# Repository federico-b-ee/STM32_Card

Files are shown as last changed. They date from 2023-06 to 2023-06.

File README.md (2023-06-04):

# STM32_Card
This is the first PCB I have designed and professionally assembled. I used KiCAD v7 and JLC PCBs' services.

# Schematic and 3D-view 

SCH
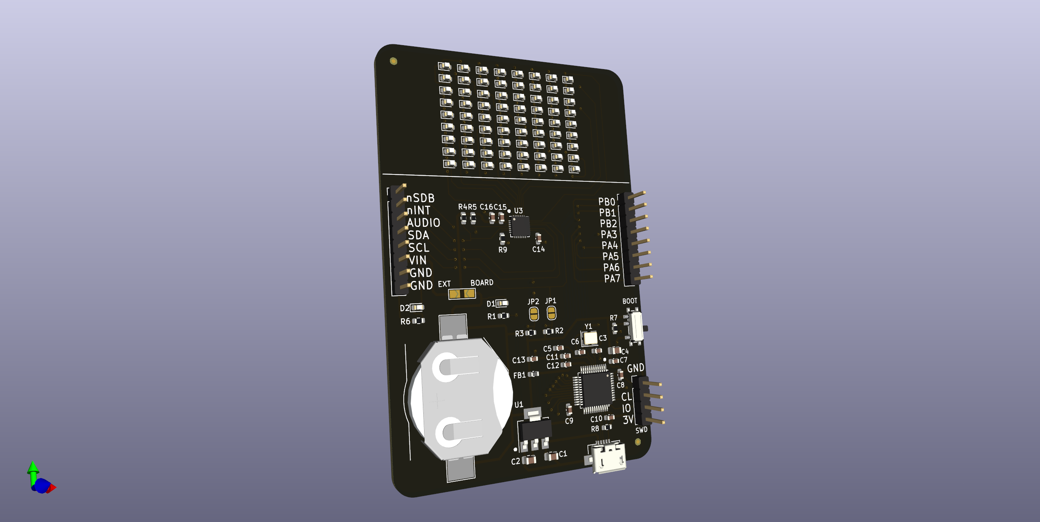
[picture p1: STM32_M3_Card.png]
3D


# Picture and Demo
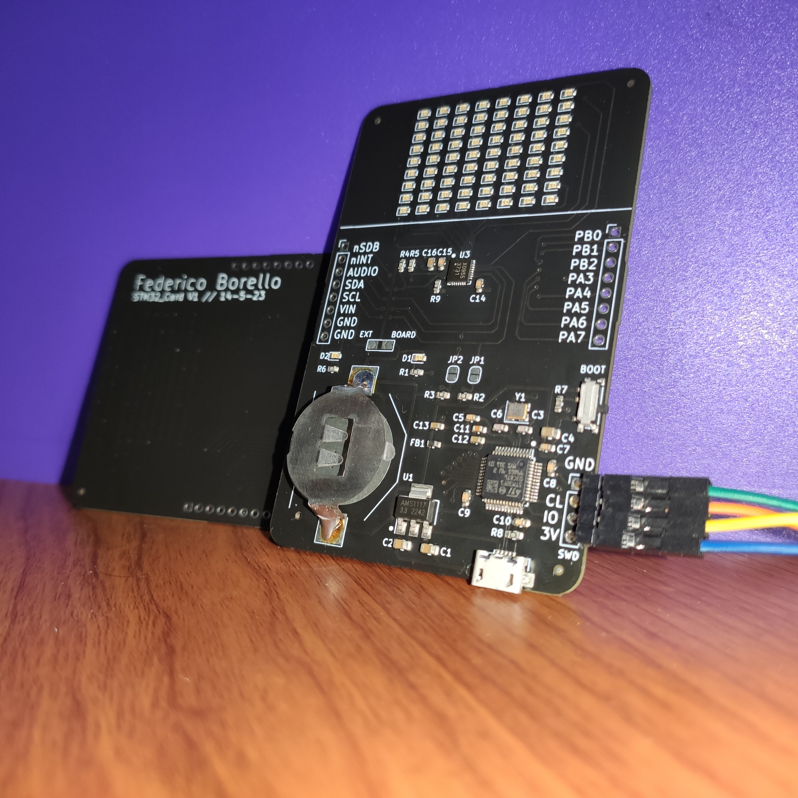
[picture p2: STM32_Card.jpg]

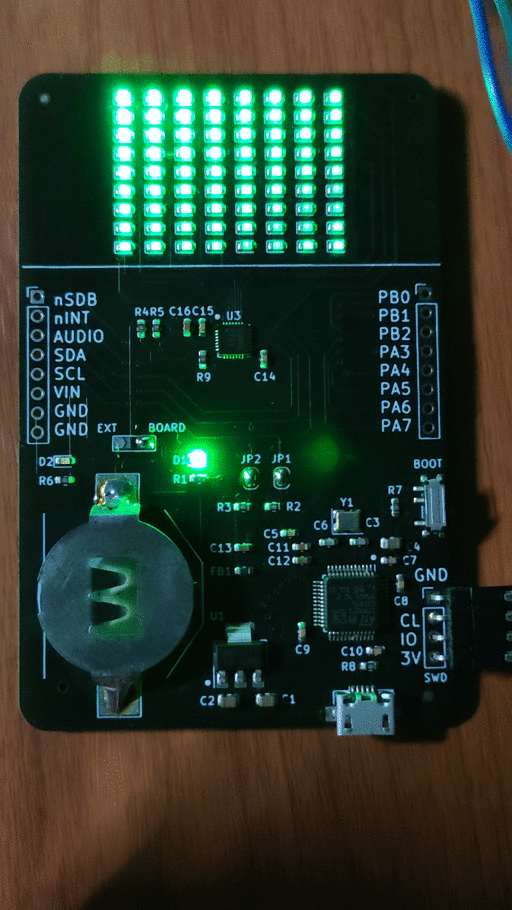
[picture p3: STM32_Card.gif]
DEMO


*Note: The gif above was made using the Adafruit's Demo:

- [Library](https://github.com/adafruit/Adafruit_IS31FL3731)
- [Overview](https://learn.adafruit.com/i31fl3731-16x9-charliplexed-pwm-led-driver/overview)

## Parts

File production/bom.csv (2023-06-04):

Designator | Footprint | Quantity | Value | LCSC Part #
C1, C2 | 0805 | 2 | 22u
C10, C14, C15, C5, C7, C8, C9 | 0603 | 7 | 100n
C11 | 0603 | 1 | 10n
C12, C13, C16 | 0603 | 3 | 1u
C3, C6 | 0603 | 2 | 10p
C4 | 0805 | 1 | 10u
D1, D10, D11, D12, D13, D14, D15, D16, D17, D18, D19, D2, D20, D21, D22, D23, D24, D25, D26, D27, D28, D29, D3, D30, D31, D32, D33, D34, D35, D36, D37, D38, D39, D4, D40, D41, D42, D43, D44, D45, D46, D47, D48, D49, D5, D50, D51, D52, D53, D54, D55, D56, D57, D58, D59, D6, D60, D61, D62, D63, D64, D65, D66, D67, D68, D69, D7, D70, D71, D72, D73, D74, D8, D9 | 0603 | 74 | LED (RED)
FB1 | 0603 | 1 | 120R | C108298
J2 | USB_Micro-B_Amphenol_10104110_Horizontal | 1 | USB_B_Micro | C2972784
JP1, JP2 | SolderJumper-2_P1.3mm_Open_RoundedPad1.0x1.5mm | 2 | SolderJumper_2_Open
JP4 | SolderJumper-3_P2.0mm_Open_TrianglePad1.0x1.5mm_NumberLabels | 1 | SolderJumper_3_Open
R1, R6 | 0603 | 2 | 680R
R2, R3, R8 | 0603 | 3 | 1k5
R4, R5, R7, R9 | 0603 | 4 | 18k
SW1 | SW_SPDT_PCM12 | 1 | SW_SPDT | C221841
U1 | SOT-223-3_TabPin2 | 1 | AMS1117-3.3 | C2992570
U2 | LQFP-48_7x7mm_P0.5mm | 1 | STM32F103C8T6 | C8734
U3 | QFN-28-1EP_4x4mm_P0.4mm_EP2.3x2.3mm | 1 | IS31FL3731-QF | C191206
Y1 | Crystal_SMD_3225-4Pin_3.2x2.5mm | 1 | 16MHz 10pF | C13738

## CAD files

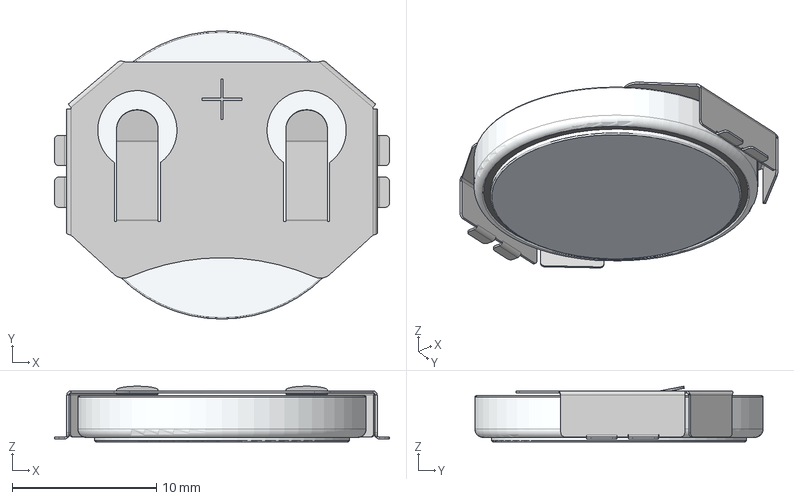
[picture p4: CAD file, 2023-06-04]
PCB/CR2032_closed_battery_BH.step
23.2 x 20.0 x 3.86 mm
cr2032 smd holder
CR2032 battery

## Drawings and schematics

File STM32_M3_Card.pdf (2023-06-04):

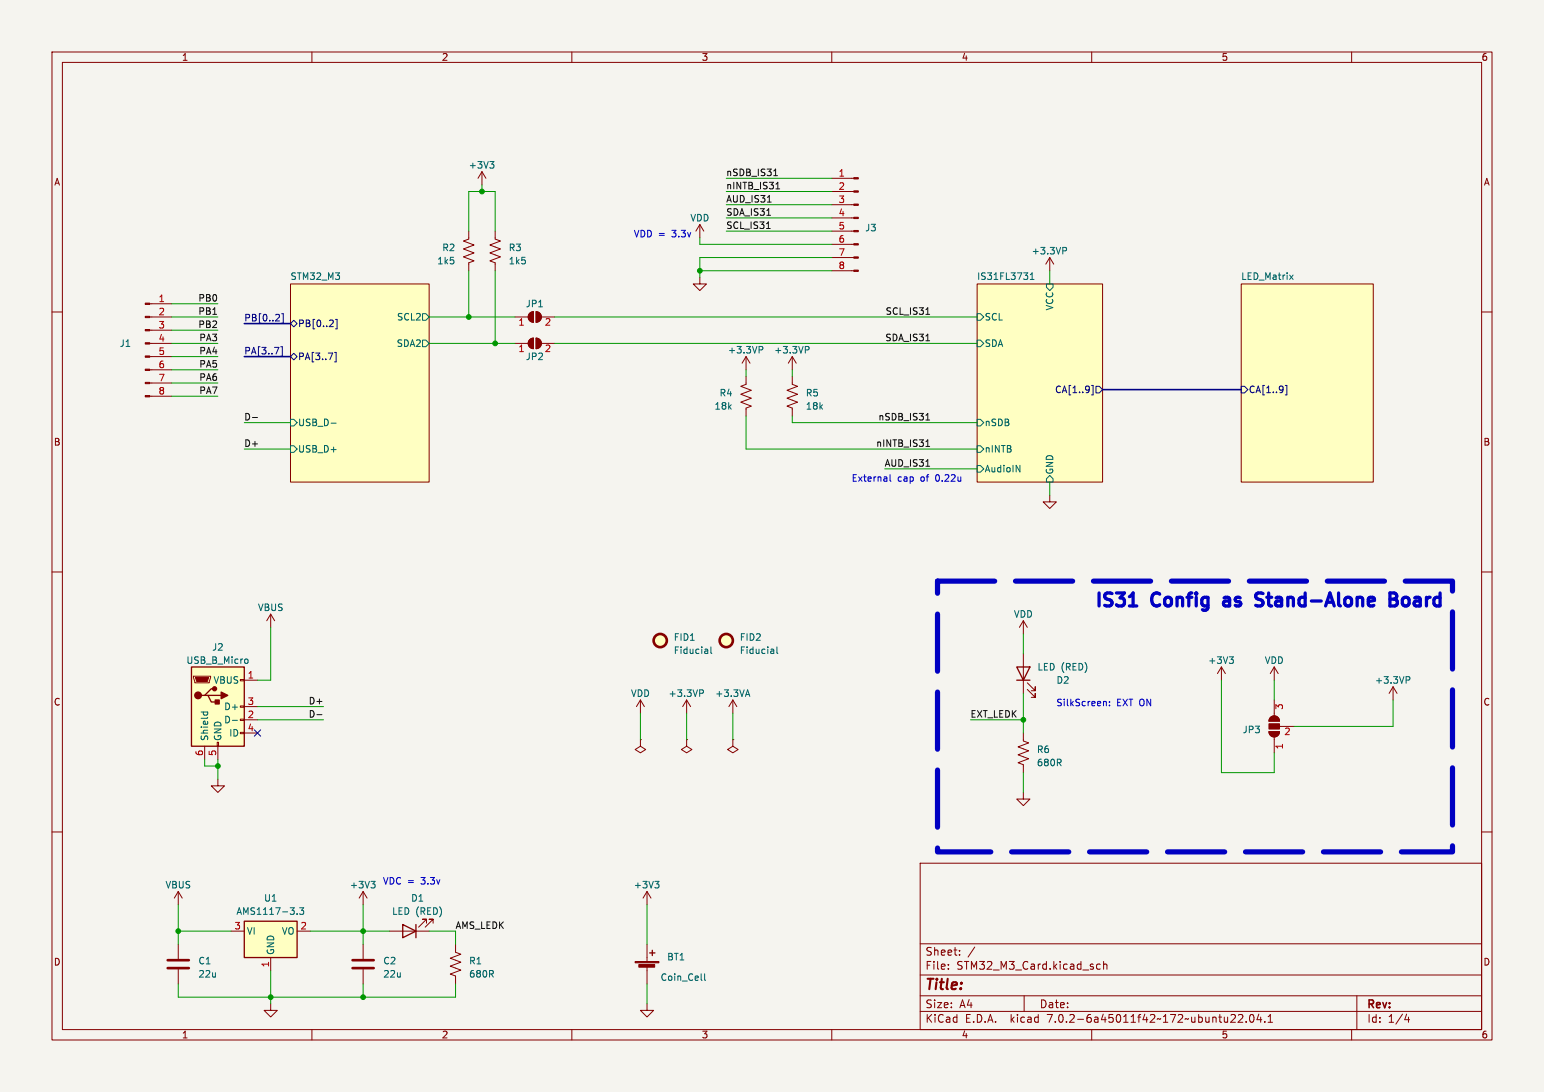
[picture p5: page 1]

Id: 1/4 Title: File: STM32_M3_Card.kicad_sch Sheet: /

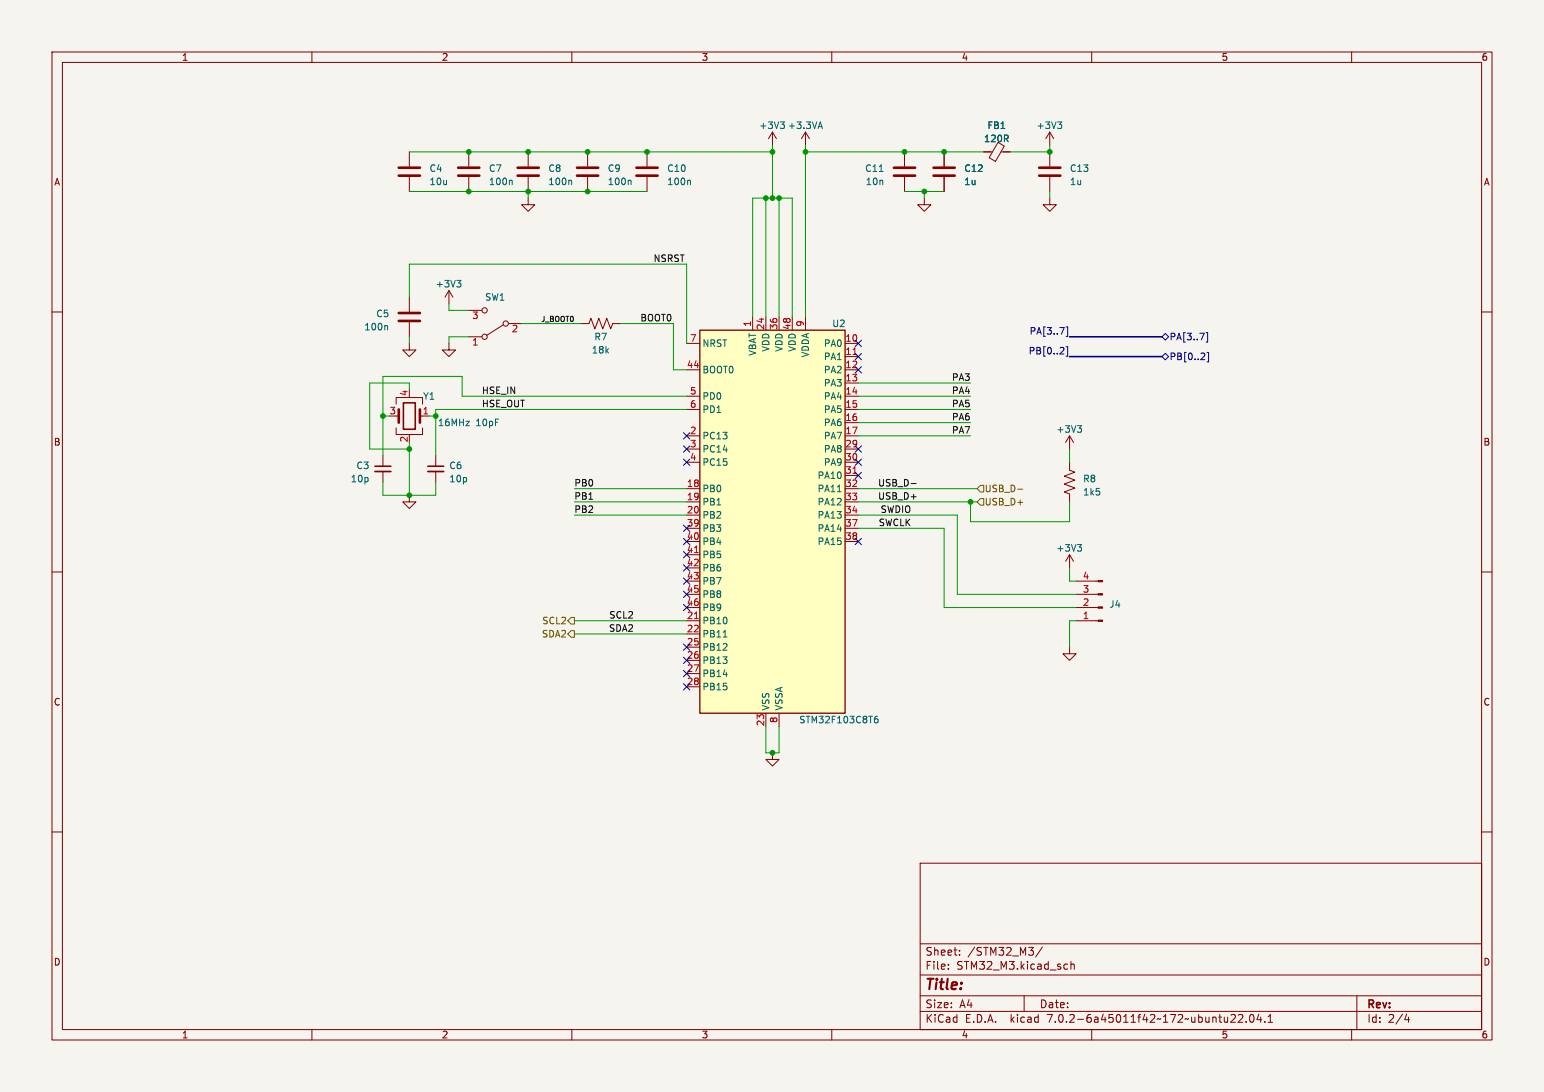
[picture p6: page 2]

1 PA0 10 PA1 11 PA2 12 PA3 13 PA4 14 PA5 15 PA6 16 PA7 17 PB0 18 PB1 19 PC13 2 PB2 20 PB10 21 PB11 22 VSS 23 VDD 24 PB12 25 PB13 26 PB14 27 PB15 28 PA8 29 PC14 3 PA9 30 PA10 31 PA11 32 PA12 33 PA13 34 VDD 36 PA14 37 PA15 38 PB3 39 PC15 4 PB4 40 PB5 41 PB6 42 PB7 43 BOOT0 44 PB8 45 PB9 46 VDD 48 PD0 5 PD1 6 NRST 7 VSSA

Id: 2/4 Title: File: STM32_M3.kicad_sch Sheet: /STM32_M3/

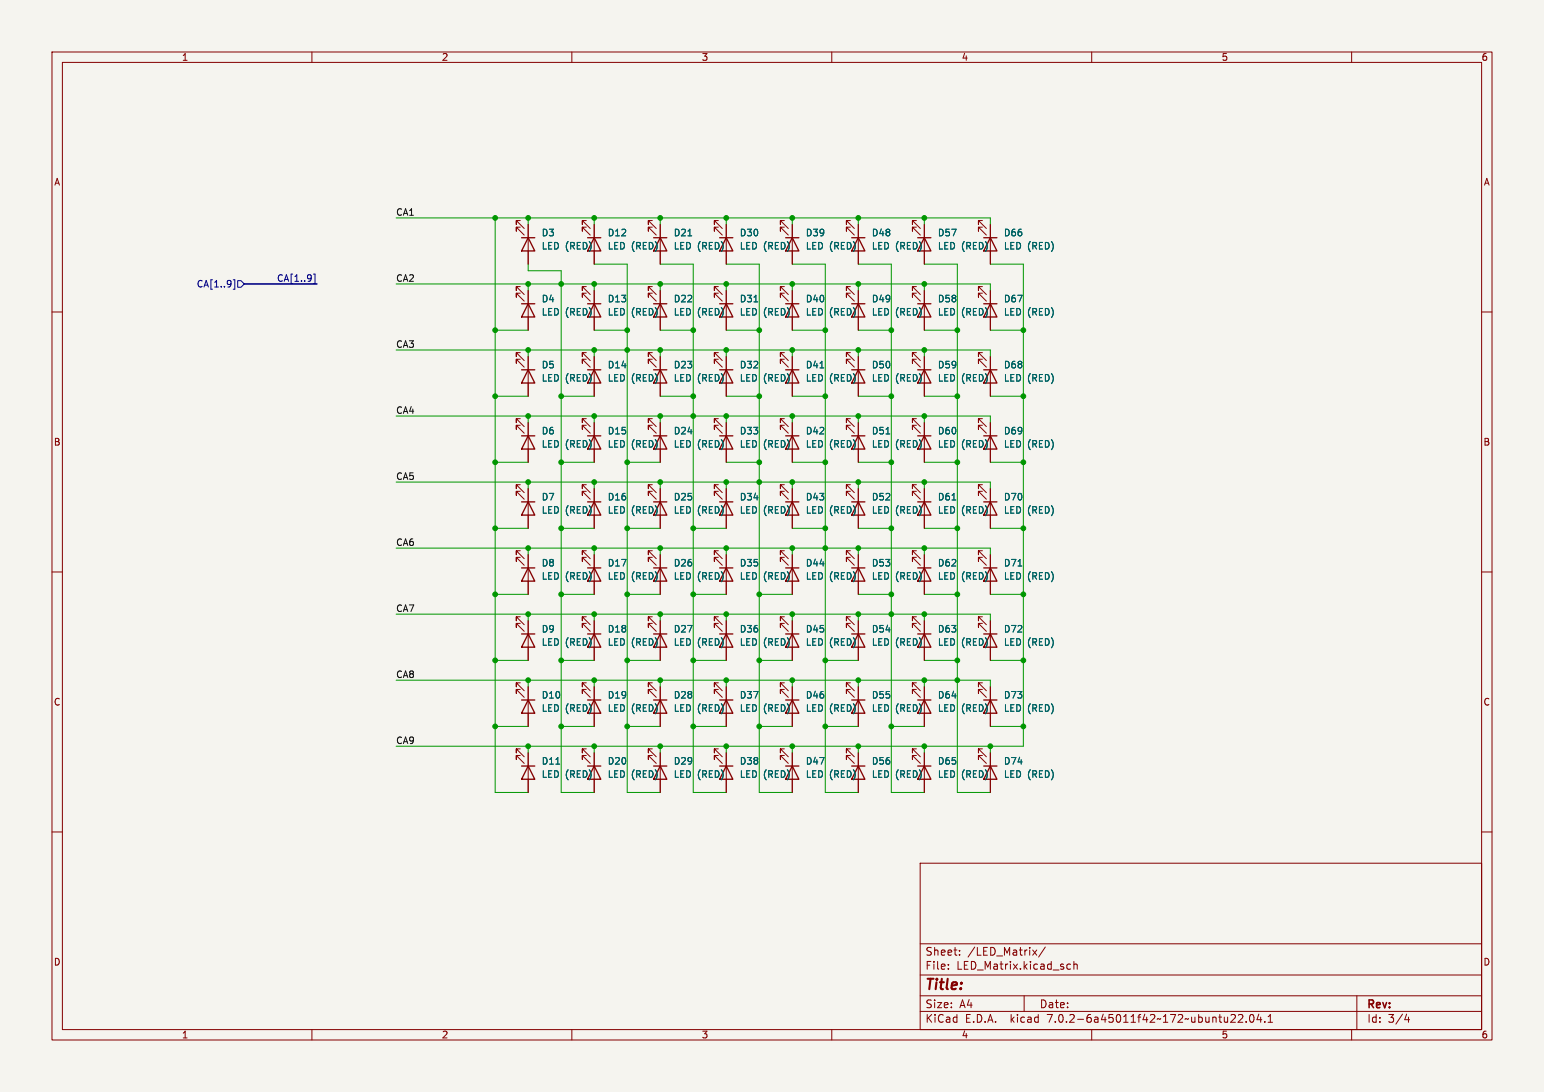
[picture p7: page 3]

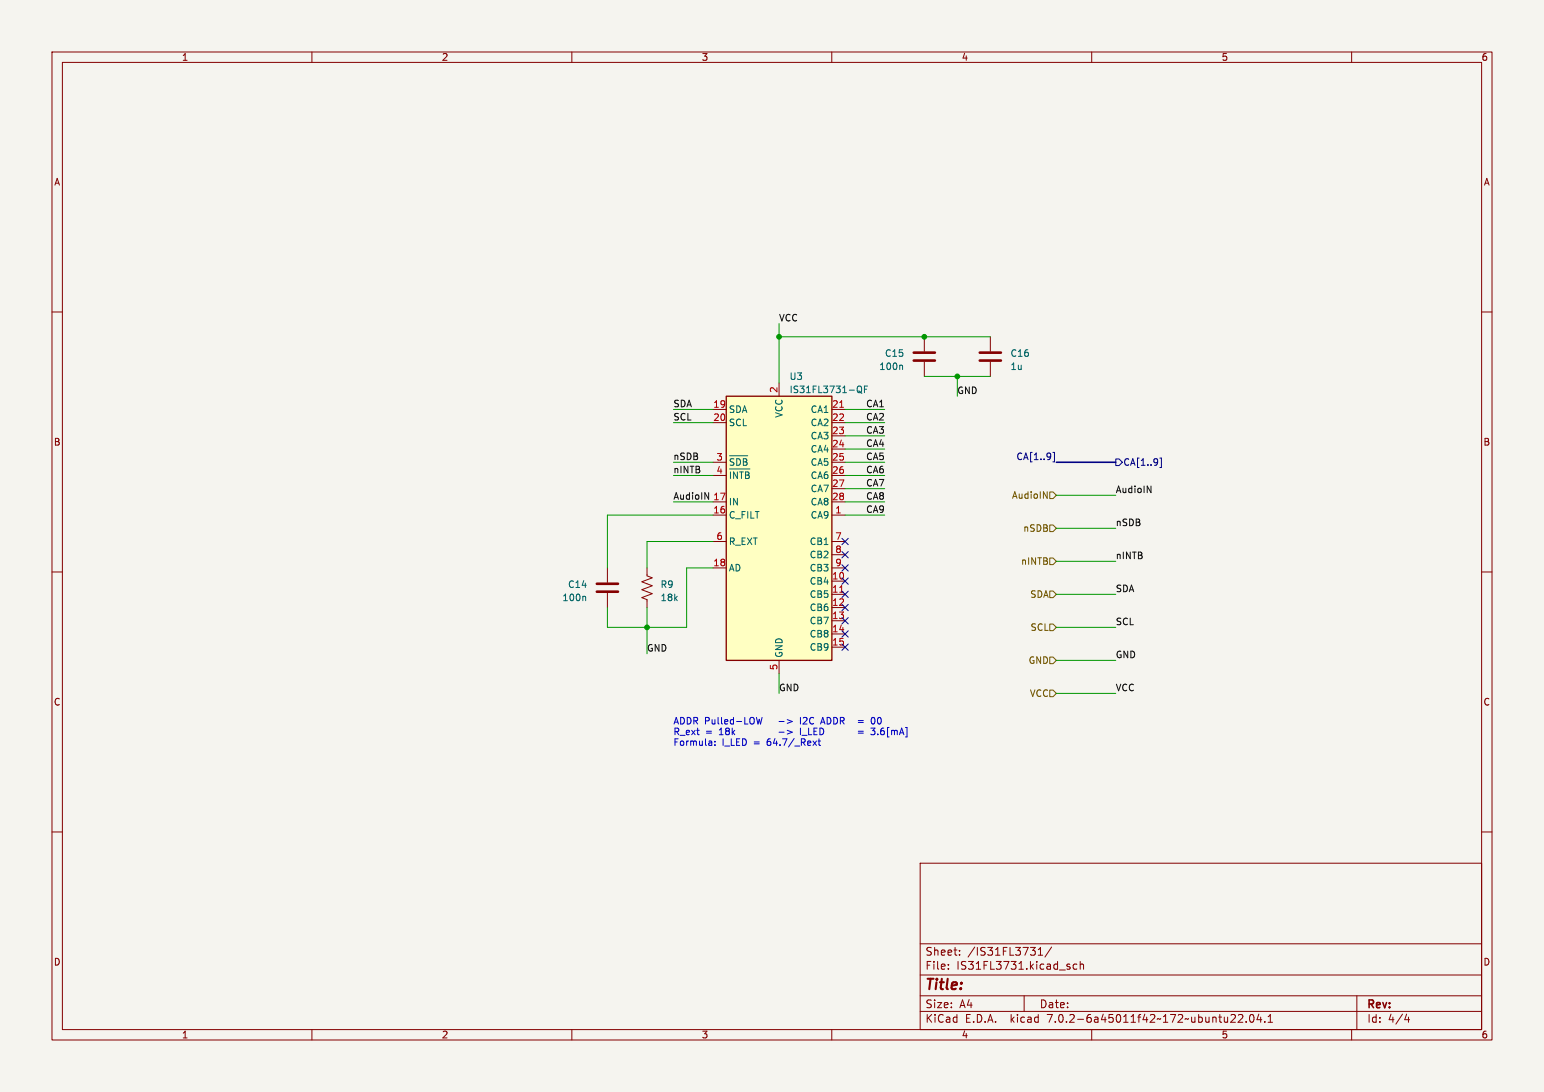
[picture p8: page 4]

2 SCL 20 CA1 21 CA2 22 CA3 23 CA4 24 CA5 25 CA6 26 CA7 27 CA8 28 ~{SDB} 3 ~{INTB} 4 GND

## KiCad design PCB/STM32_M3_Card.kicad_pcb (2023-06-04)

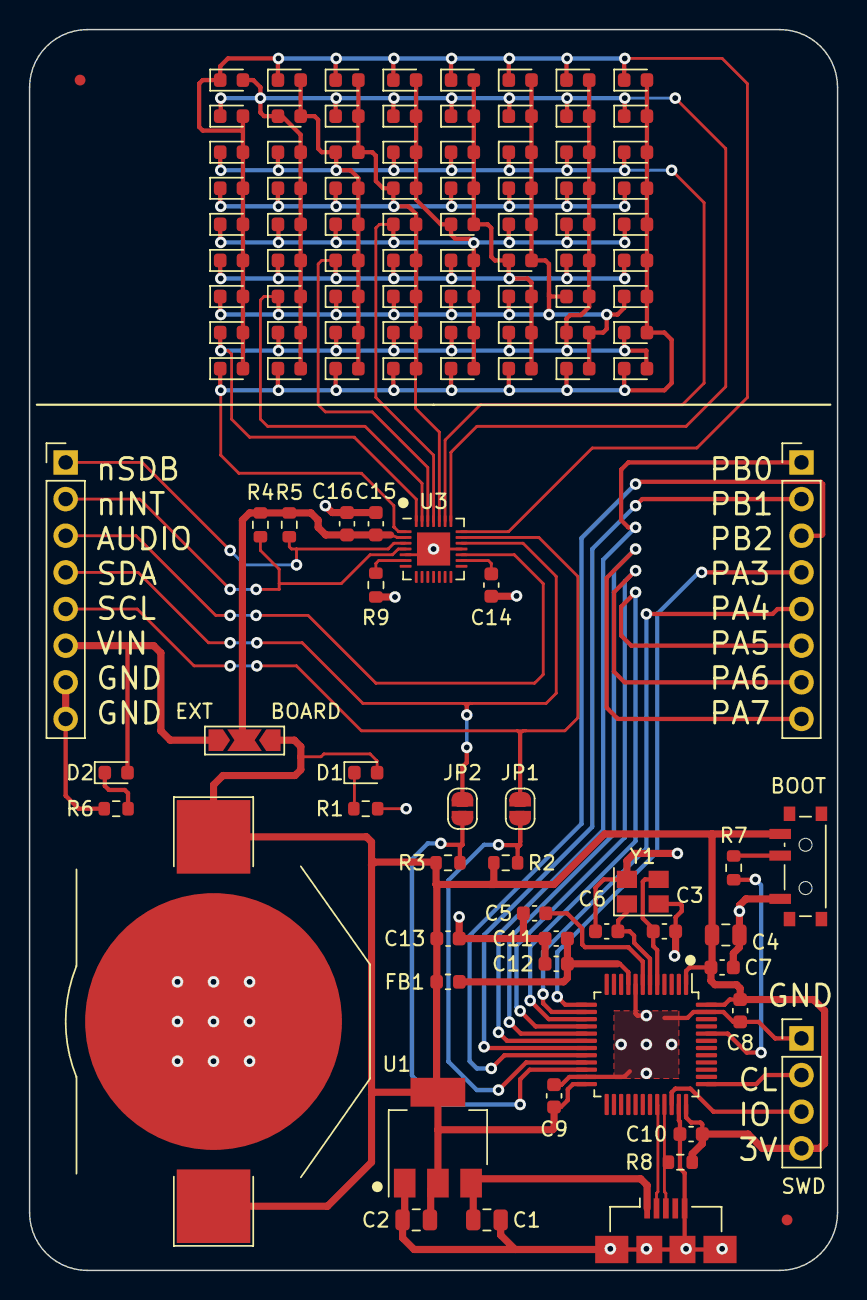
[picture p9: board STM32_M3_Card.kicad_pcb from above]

Board: 2 copper layers, 56.0 x 86.0 mm, 115 parts (0 on the bottom side), 43 nets.

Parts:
BT1: Coin_Cell; BatteryHolder_Keystone_3002_1x2032
C1, C2: 22u; C_0805_2012Metric
C3, C6: 10p; C_0603_1608Metric
C4: 10u; C_0805_2012Metric
C5, C7, C8, C9, C10, C14, C15: 100n; C_0603_1608Metric
C11: 10n; C_0603_1608Metric
C12, C13, C16: 1u; C_0603_1608Metric
D1, D2, D3, D4, D5, D6, D7, D8, D9, D10, D11, D12, D13, D14, D15, D16, D17, D18, D19, D20, D21, D22, D23, D24, D25, D26, D27, D28, D29, D30, D31, D32, D33, D34, D35, D36, D37, D38, D39, D40, D41, D42, D43, D44, D45, D46, D47, D48, D49, D50, D51, D52, D53, D54, D55, D56, D57, D58, D59, D60, D61, D62, D63, D64, D65, D66, D67, D68, D69, D70, D71, D72, D73, D74: LED (RED); LED_0603_1608Metric
FB1: 120R; L_0603_1608Metric
FID1, FID2: Fiducial; Fiducial_0.75mm_Mask1.5mm
J1, J3: Conn_01x08_Pin; PinHeader_1x08_P2.54mm_Vertical
J2: USB_B_Micro; USB_Micro-B_Amphenol_10104110_Horizontal
J4: Conn_01x04_Pin; PinHeader_1x04_P2.54mm_Vertical
JP1, JP2: SolderJumper_2_Open; SolderJumper-2_P1.3mm_Open_RoundedPad1.0x1.5mm
JP3: SolderJumper_3_Open; SolderJumper-3_P2.0mm_Open_TrianglePad1.0x1.5mm_NumberLabels
R1, R6: 680R; R_0603_1608Metric
R2, R3, R8: 1k5; R_0603_1608Metric
R4, R5, R7, R9: 18k; R_0603_1608Metric
SW1: SW_SPDT; SW_SPDT_PCM12
U1: AMS1117-3.3; SOT-223-3_TabPin2
U2: STM32F103C8T6; LQFP-48_7x7mm_P0.5mm
U3: IS31FL3731-QF; QFN-28-1EP_4x4mm_P0.4mm_EP2.3x2.3mm
Y1: 16MHz 10pF; Crystal_SMD_3225-4Pin_3.2x2.5mm

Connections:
+3.3VA: C11.1, C12.1, FB1.1, U2.9 (VDDA)
+3.3VP: C15.1, C16.1, JP3.2 (C), R4.1, R5.1, U3.2 (VCC)
+3V3: BT1.1 (+), C2.1, C4.1, C7.1, C8.1, C9.1, C10.1, C13.1, D1.2 (A), FB1.2, J4.4, JP3.1 (A), R2.1, R3.1, R8.1, SW1.3 (C), U1.2 (VO), U2.1 (VBAT), U2.24 (VDD), U2.36 (VDD), U2.48 (VDD)
/AMS_LEDK: D1.1 (K), R1.2
/AUD_IS31: J3.3, U3.17 (IN)
/D+: J2.3 (D+), R8.2, U2.33 (PA12)
/D-: J2.2 (D-), U2.32 (PA11)
/EXT_LEDK: D2.1 (K), R6.2
/IS31FL3731/CA1: D3.1 (K), D4.2 (A), D5.2 (A), D6.2 (A), D7.2 (A), D8.2 (A), D9.2 (A), D10.2 (A), D11.2 (A), D12.1 (K), D21.1 (K), D30.1 (K), D39.1 (K), D48.1 (K), D57.1 (K), D66.1 (K), U3.21 (CA1)
/IS31FL3731/CA2: D3.2 (A), D4.1 (K), D13.1 (K), D14.2 (A), D15.2 (A), D16.2 (A), D17.2 (A), D18.2 (A), D19.2 (A), D20.2 (A), D22.1 (K), D31.1 (K), D40.1 (K), D49.1 (K), D58.1 (K), D67.1 (K), U3.22 (CA2)
/IS31FL3731/CA3: D5.1 (K), D12.2 (A), D13.2 (A), D14.1 (K), D23.1 (K), D24.2 (A), D25.2 (A), D26.2 (A), D27.2 (A), D28.2 (A), D29.2 (A), D32.1 (K), D41.1 (K), D50.1 (K), D59.1 (K), D68.1 (K), U3.23 (CA3)
/IS31FL3731/CA4: D6.1 (K), D15.1 (K), D21.2 (A), D22.2 (A), D23.2 (A), D24.1 (K), D33.1 (K), D34.2 (A), D35.2 (A), D36.2 (A), D37.2 (A), D38.2 (A), D42.1 (K), D51.1 (K), D60.1 (K), D69.1 (K), U3.24 (CA4)
/IS31FL3731/CA5: D7.1 (K), D16.1 (K), D25.1 (K), D30.2 (A), D31.2 (A), D32.2 (A), D33.2 (A), D34.1 (K), D43.1 (K), D44.2 (A), D45.2 (A), D46.2 (A), D47.2 (A), D52.1 (K), D61.1 (K), D70.1 (K), U3.25 (CA5)
/IS31FL3731/CA6: D8.1 (K), D17.1 (K), D26.1 (K), D35.1 (K), D39.2 (A), D40.2 (A), D41.2 (A), D42.2 (A), D43.2 (A), D44.1 (K), D53.1 (K), D54.2 (A), D55.2 (A), D56.2 (A), D62.1 (K), D71.1 (K), U3.26 (CA6)
/IS31FL3731/CA7: D9.1 (K), D18.1 (K), D27.1 (K), D36.1 (K), D45.1 (K), D48.2 (A), D49.2 (A), D50.2 (A), D51.2 (A), D52.2 (A), D53.2 (A), D54.1 (K), D63.1 (K), D64.2 (A), D65.2 (A), D72.1 (K), U3.27 (CA7)
/IS31FL3731/CA8: D10.1 (K), D19.1 (K), D28.1 (K), D37.1 (K), D46.1 (K), D55.1 (K), D57.2 (A), D58.2 (A), D59.2 (A), D60.2 (A), D61.2 (A), D62.2 (A), D63.2 (A), D64.1 (K), D73.1 (K), D74.2 (A), U3.28 (CA8)
/IS31FL3731/CA9: D11.1 (K), D20.1 (K), D29.1 (K), D38.1 (K), D47.1 (K), D56.1 (K), D65.1 (K), D66.2 (A), D67.2 (A), D68.2 (A), D69.2 (A), D70.2 (A), D71.2 (A), D72.2 (A), D73.2 (A), D74.1 (K), U3.1 (CA9)
/PA3: J1.4, U2.13 (PA3)
/PA4: J1.5, U2.14 (PA4)
/PA5: J1.6, U2.15 (PA5)
/PA6: J1.7, U2.16 (PA6)
/PA7: J1.8, U2.17 (PA7)
/PB0: J1.1, U2.18 (PB0)
/PB1: J1.2, U2.19 (PB1)
/PB2: J1.3, U2.20 (PB2)
/SCL_IS31: J3.5, JP1.2 (B), U3.20 (SCL)
/SDA_IS31: J3.4, JP2.2 (B), U3.19 (SDA)
/STM32_M3/BOOT0: R7.2, U2.44 (BOOT0)
/STM32_M3/HSE_IN: C3.1, U2.5 (PD0), Y1.3
/STM32_M3/HSE_OUT: C6.1, U2.6 (PD1), Y1.1
/STM32_M3/J_BOOT0: R7.1, SW1.2 (B)
/STM32_M3/NSRST: C5.1, U2.7 (NRST)
/STM32_M3/SCL2: JP1.1 (A), R2.2, U2.21 (PB10)
/STM32_M3/SDA2: JP2.1 (A), R3.2, U2.22 (PB11)
/STM32_M3/SWCLK: J4.2, U2.37 (PA14)
/STM32_M3/SWDIO: J4.3, U2.34 (PA13)
/nINTB_IS31: J3.2, R4.2, U3.4 (~INTB)
/nSDB_IS31: J3.1, R5.2, U3.3 (~SDB)
GND: BT1.2 (-), C1.2, C2.2, C3.2, C4.2, C5.2, C6.2, C7.2, C8.2, C9.2, C10.2, C11.2, C12.2, C13.2, C14.2, C15.2, C16.2, J2.5 (GND), J2.6 (Shield), J3.7, J3.8, J4.1, R1.1, R6.1, R9.2, SW1.1 (A), U1.1 (GND), U2.8 (VSSA), U2.23 (VSS), U2.35 (VSS), U2.47 (VSS), U3.5 (GND), U3.18 (AD), U3.29 (GND), Y1.2, Y1.4
unnamed: C14.1, U3.16 (C_FILT)
unnamed: R9.1, U3.6 (R_EXT)
VBUS: C1.1, J2.1 (VBUS), U1.3 (VI)
VDD: D2.2 (A), J3.6, JP3.3 (B)
